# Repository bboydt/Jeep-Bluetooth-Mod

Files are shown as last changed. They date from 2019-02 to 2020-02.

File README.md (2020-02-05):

# Jeep Bluetooth Mod

## About
When I started driving, I wanted Bluetooth in my 2004 Jeep Grand Cherokee. Several years later, I finally got around to building a Bluetooth mod. My radio has a plug for a cd changer, so I used an Arduino and a Bluetooth module to make a pseudo cd changer. It took me about a month, however I procrastinated a lot. [Here's a video of the prototype working (ignore the awful music)](https://youtu.be/_DS7fCqb5ws).

## Useful Info

 - The arduino prototype code is in Jeep/ and the ATtiny version's code is in src/
 - My radio model is p05064354aj.
 - I'm using an Arduino UNO and a XS-3868 Bluetooth module
 - Chrysler radios, made before 2004, use the car’s internal PCI bus for communication with other accessories (i.e. a cd changer). It’s a good idea to be careful when writing to this bus because you could damage your car.
 - My car uses the J1850 VPW protocol.
 - Some good vocabulary to know for this protocol:
    - **Frame** : a packet of data
    - **Cyclical Redundancy Check (CRC)** : it’s a checksum
 - I used two optocouplers to communicate on the bus without frying my Arduino. Also, I put some LEDs on the optocouplers' outputs which was useful for debugging.

## Useful Links

 - [This has a lot of information on what to send to the radio to trick it into thinking you’re a cd changer.](https://www.mictronics.de/projects/cdc-protocols/#ChryslerJeep)
 - [This has good info on the J1850 protocol.](http://www.interfacebus.com/Automotive_SAE_J1850_Bus.html)
 - [A more technical document on J1850.](http://citeseerx.ist.psu.edu/viewdoc/download?doi=10.1.1.506.6682&rep=rep1&type=pdf)
 - [This guy’s project uses the same protocol so it was helpful.](https://github.com/connorwm/J1850VPW)
 - [Radio Pinout (there are also other radio pinouts here)](https://www.tehnomagazin.com/Auto-radio-car-connector/CHRYSLER-Car-Radio-Wiring-Connector.htm)

## Todo

 - Finish converting from the Arduino prototype to the ATtiny version
   - CRC check (Frame Creation in general)
   - Proper Responses to the radio
 - In the current configuration, the relay is unreliable so that needs to be fixed

----

*Benjamin Thomas - boydbt48@gmail.com - 2019*

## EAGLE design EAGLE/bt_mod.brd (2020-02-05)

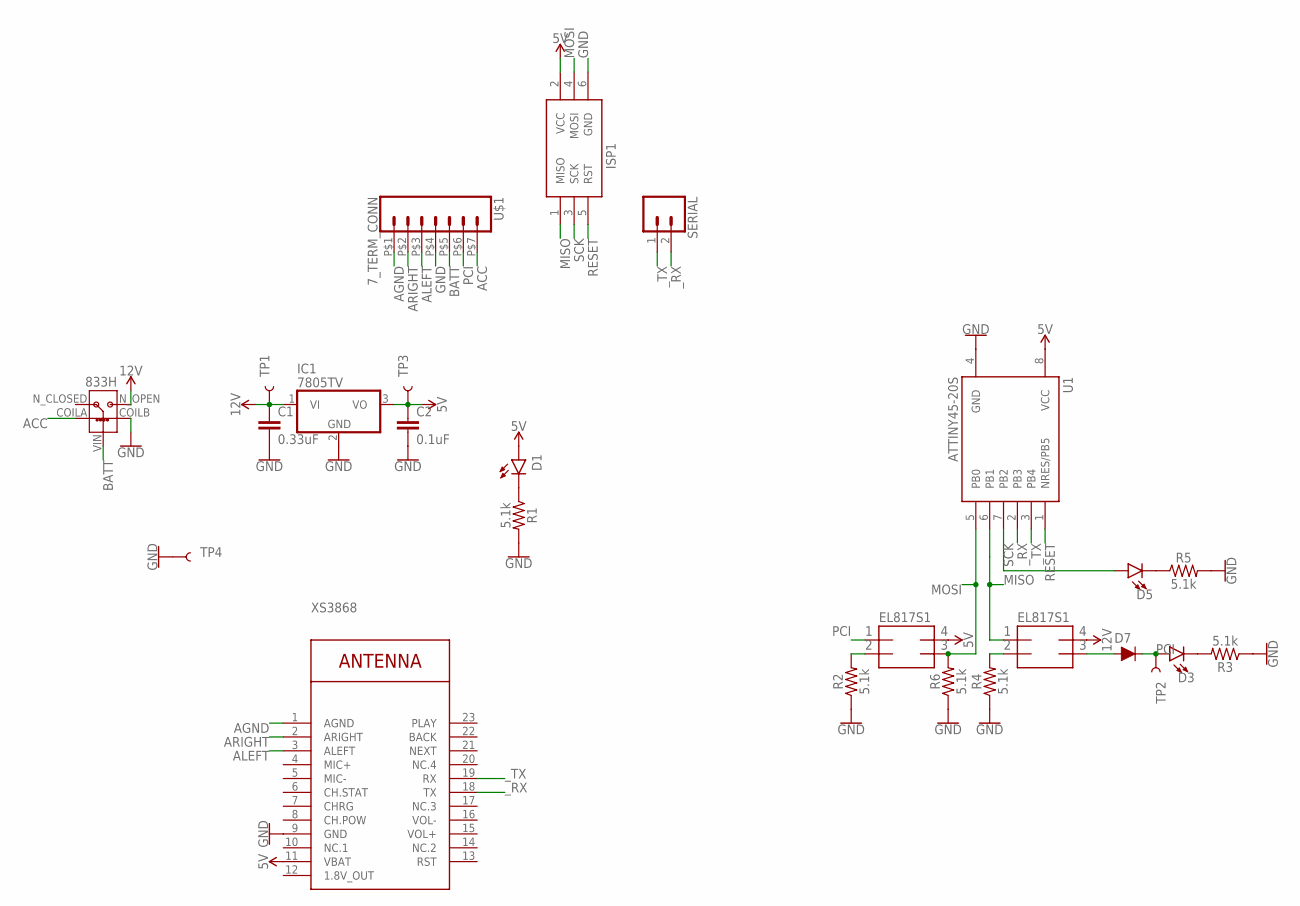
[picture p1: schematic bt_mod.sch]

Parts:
1: 833H-1C-C-12VDC
C1: 0.33uF; 0603
C2: 0.1uF; 0603
D1, D3, D5: LED0603; LED-0603
D7: 250mA/100V; SOD-323
IC1: 7805TV; TO220V
INPUT: EL3H7-G; SMD-4
ISP1: AVRISP-6; AVRISP
OUTPUT: EL3H7-G; SMD-4
R1, R2, R3, R4, R5, R6: 5.1k; 0603
SERIAL: CONN_02; 1X02
TP1, TP2, TP3, TP4: TEST-POINT3X5; PAD.03X.05
U1: ATTINY45-20S; SOIC8_EIAJ_208MIL
U$1: 7_TERM_CONN; 7_TERMINALS
XS3868: WIRELESS-BLUETOOTH-XS3868

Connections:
1.8V_OUT: XS3868.12 (1.8V_OUT)
5V: C2.1, D1.A, IC1.3 (VO), INPUT.P$4, ISP1.2 (VCC), TP3.P$1, U1.8 (VCC), XS3868.11 (VBAT)
12V: 1.N_OPEN, C1.1, IC1.1 (VI), OUTPUT.P$4, TP1.P$1
ACC: 1.COILA, U$1.P$7 (7)
AGND: U$1.P$1 (1), XS3868.1 (AGND)
ALEFT: U$1.P$3 (3), XS3868.3 (ALEFT)
ARIGHT: U$1.P$2 (2), XS3868.2 (ARIGHT)
BATT: 1.VIN, U$1.P$5 (5)
GND: 1.COILB, C1.2, C2.2, IC1.2 (GND), ISP1.6 (GND), R1.2, R2.1, R3.1, R4.1, R5.2, R6.1, TP4.P$1, U1.4 (GND), U$1.P$4 (4), XS3868.9 (GND)
MISO: ISP1.1 (MISO), OUTPUT.P$1, U1.6 (PB1)
MOSI: INPUT.P$3, ISP1.4 (MOSI), R6.2, U1.5 (PB0)
unnamed: D1.C, R1.1
unnamed: INPUT.P$2, R2.2
unnamed: OUTPUT.P$2, R4.2
unnamed: D5.C, R5.1
unnamed: D3.C, R3.2
unnamed: D7.A, OUTPUT.P$3
PCI: D3.A, D7.C, INPUT.P$1, TP2.P$1, U$1.P$6 (6)
RESET: ISP1.5 (RST), U1.1 (NRES/PB5)
RST: XS3868.13 (RST)
SCK: D5.A, ISP1.3 (SCK), U1.7 (PB2)
_RX: SERIAL.2, U1.2 (PB3), XS3868.18 (TX)
_TX: SERIAL.1, U1.3 (PB4), XS3868.19 (RX)

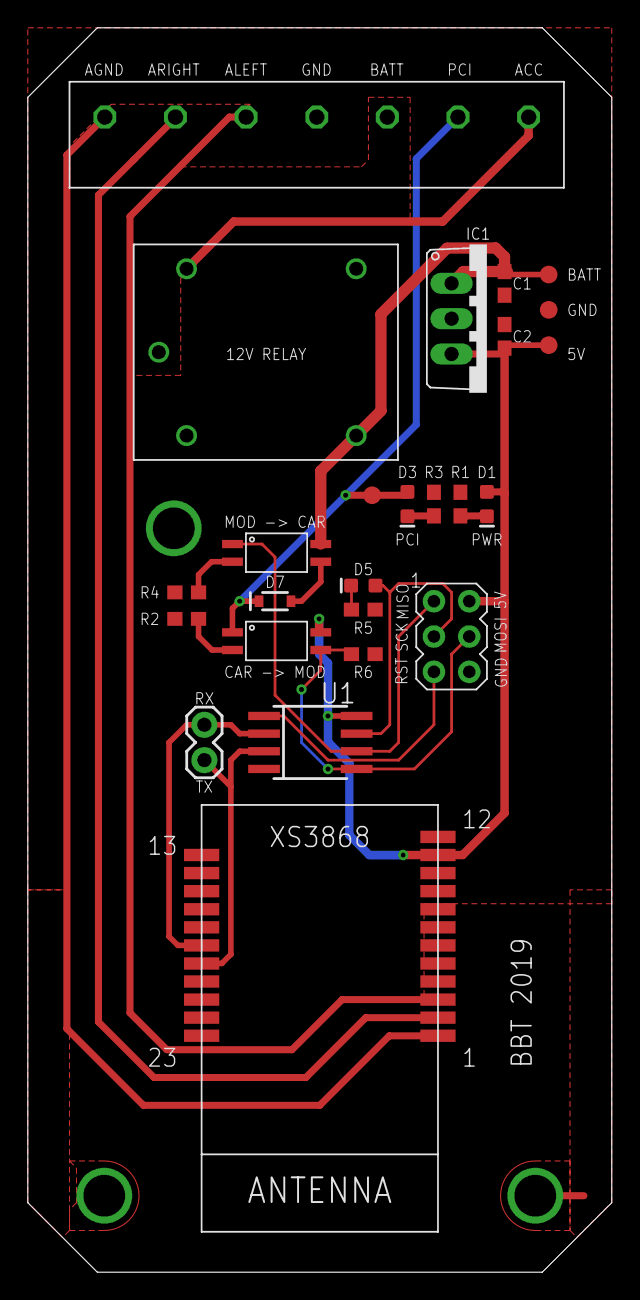
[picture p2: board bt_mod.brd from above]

Board: 2 copper layers, 42.0 x 89.5 mm, 25 parts (0 on the bottom side), 21 nets.

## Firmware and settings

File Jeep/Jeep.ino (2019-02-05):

// Jeep.ino
// Benjamin Thomas
// boydbt48@gmail.com
// Jan 2019
// A script that allows an Arduino to become a fake CD changer for a 2004 Jeep Grand Cherokee Radio.
// https://github.com/TildeOrange/Jeep-Bluetooth-Mod


// #define DEBUG_OUTPUT // Uncomment if you want debug info (might be slower)

#define PIN_IN 6
#define PIN_OUT 7
#define ERROR_TIMEDOUT -1
#define ERROR_INVALID_CRC -2

#define BUFF_LEN 16
byte buff[BUFF_LEN];

unsigned long last_sent = 0;

void setup()
{
#ifdef DEBUG_OUTPUT
	Serial.begin(9600);
#endif // DEBUG_OUTPUT

	pinMode(PIN_IN, INPUT);
	pinMode(PIN_OUT, OUTPUT);
	digitalWrite(PIN_OUT, LOW);
}

// A simple loop that checks for a poll frame from the radio and responds as if it was a CD changer. This opens up the audio input.
void loop()
{
	digitalWrite(PIN_OUT, LOW);   // just to be safe

	int bytes_read = read_frame(PIN_IN, buff, BUFF_LEN, 2000); // read from PIN_IN into the buff and timeout after 2 seconds

	if (0 < bytes_read && bytes_read <= 12)   // TODO figure out max length of frame
	{

#ifdef DEBUG_OUTPUT
        // print incoming frame (without check sum)
		Serial.print("Incoming frame: [ ");
		for (int i = 0; i < bytes_read - 1; i++)
		{
			Serial.print("0x" + String(buff[i], HEX) + " ");
		}
		Serial.println("]");
#endif // DEBUG_OUTPUT


		unsigned long current_time = millis();

		// If received frame is a poll from the radio or we haven't sent anything for a bit, then send a response frame.
		if (buff[0] == 0x8D || current_time - last_sent >= 1000)
		{
			int len = 5;
			byte buff[len] = { 0x8D, 0x94, 0x4, 0x14 };
			buff[len - 1] = CRC8(buff, len - 1);


#ifdef DEBUG_OUTPUT
            // print outgoing frame (with CRC)
			Serial.print("Outgoing frame: [ ");
			for (int i = 0; i < len; i++)
			{
				Serial.print("0x" + String(buff[i], HEX) + " ");
			}
			Serial.println("]");
#endif // DEBUG_OUTPUT

            // TODO wait for a quiet moment

			send_frame(PIN_OUT, buff, len);

			last_sent = current_time;
		}
	}
	else
	{
		switch (bytes_read)
		{
		case ERROR_TIMEDOUT:
			Serial.println("Timed out");
			break;
		case ERROR_INVALID_CRC:
			Serial.print("Read frame with an invalid CRC: [");
			for (int i = 0; i < 4; i++)
			{
				Serial.print("0x" + String(buff[i], HEX) + " ");
			}
			Serial.println("]");
			break;
		default:
			Serial.println("Read too many/few bytes" + String(bytes_read));
			break;
		}
	}
	//*/
}

// Disclaimer:
// This is a copy of a function written by Michael Wolf for the AVR J1850 VPW Interface he wrote. (https://www.mictronics.de/projects/j1850-vpw-interface/)
// I do not understand this so best of luck to you if it breaks.
//
// Creates an 8 bit cyclical redundancy check (CRC) from a bunch of bytes.
// The CRC can be used to check the validaty of those bytes durring transmission and is used to verify received data.
//
// byte *buff : data used to create CRC
// int len    : length of data
byte CRC8(byte *buff, int len)
{
	byte crc_reg = 0xff;
	byte poly;
	byte byte_count;
	byte bit_count;
	byte *byte_point;
	byte bit_point;

	for (byte_count = 0, byte_point = buff; byte_count < len; ++byte_count, ++byte_point)
	{
		for (bit_count = 0, bit_point = 0x80; bit_count < 8; ++bit_count, bit_point >>= 1)
		{
			if (bit_point & *byte_point)         // case for new bit = 1
			{
				if (crc_reg & 0x80)
				{
					poly = 1;             // define the polynomial
				}
				else
				{
					poly = 0x1c;
				}

				crc_reg = ((crc_reg << 1) | 1) ^ poly;
			}
			else         // case for new bit = 0
			{
				poly = 0;
				if (crc_reg & 0x80)
				{
					poly = 0x1d;
				}
				crc_reg = (crc_reg << 1) ^ poly;
			}
		}
	}
	return ~crc_reg;
}

// TODO remove this complicated mess
//
// Measures how long, in microseconds, a voltage was held.
// Blocks until the pin's voltage changes or the timeout is reached.
// Returns the time in microseconds that the voltage was constant.
//
// int pin                  : the pin to watch
// int initial_voltage      : what the voltage currenly is
// unsigned long start_time : when the voltage first became the initial voltage in microseconds (set to 0 if you aren't too concerned about accruacy)
// unsigned long timeout    : how many microseconds is too long to wait (warning: using this will add some overhead and decrease accruacy)
unsigned long get_signal_length(int pin, int initial_voltage, unsigned long start_time, unsigned long timeout)
{
	unsigned long start = start_time != 0 ? start_time : micros();

	if (timeout > 0)
	{
		unsigned long elapsed_time;

		// wait for voltage to change
		while (digitalRead(pin) == initial_voltage && elapsed_time < timeout)
		{
			elapsed_time = micros() - start;
		}

		return elapsed_time;
	}
	else
	{
		while (digitalRead(pin) == initial_voltage) {}
		return micros() - start;
	}
}

// Bit Symbols Cheat Sheet
// High for 64uS  = 1
// Low  for 128uS = 1
// High for 128uS = 0
// Low  for 64uS  = 0

// Reads a frame into a byte buffer.
// Blocks until a response was found or the timeout is reached.
// Returns the number of bytes read or ERROR_TIMEDOUT if the timeout was reached.
//
// int pin               : the pin to watch
// byte *buff            : the buffer to write into
// int len               : the length of the buffer
// unsigned long timeout : how many milliseconds is too long to wait
int read_frame(int pin, byte *buff, int len, unsigned long timeout)
{
	unsigned long start_time = millis();
	bool found_EOD = false;
	unsigned long signal_length;
	unsigned long signal_end = 0L;
	int current_voltage = LOW;   // we expect this to be low after the SOF signal
	String bits_str = "";

	// look for SOF signal (high for 200uS)
	while (signal_end == 0L)
	{
		while (digitalRead(pin) != HIGH)
		{
			if (millis() - start_time >= timeout)
			{
				return ERROR_TIMEDOUT;
			}
		}

		signal_length = get_signal_length(pin, HIGH, 0, timeout);

		if (abs(signal_length - 200) <= 15)     // if the signal length was 200uS +/- 15uS, then this is a valid signal
		{
			signal_end = micros();
			break;
		}

		if (millis() - start_time >= timeout)
		{
			return ERROR_TIMEDOUT;
		}
	}

	while (!found_EOD)
	{
		current_voltage = digitalRead(PIN_IN);
		signal_length = get_signal_length(pin, current_voltage, signal_end, 300);
		signal_end = micros();

		if (signal_length <= 96)
		{
			if (current_voltage == HIGH)
			{
				bits_str += '1';
			}
			else
			{
				bits_str += '0';
			}
		}
		else if (signal_length <= 164)
		{
			if (current_voltage == LOW)
			{
				bits_str += '1';
			}
			else
			{
				bits_str += '0';
			}
		}
		else if (current_voltage == LOW && signal_length > 164)
		{
			found_EOD = true;
		}
	}

	// parse data
	size_t bit_count = bits_str.length();
	size_t byte_count = bit_count / 8;

	for (int p = 0; p < byte_count; p++)
	{
		for (int b = p * 8; b < (p + 1) * 8; b++)
		{
			buff[p] <<= 1;
			if (bits_str[b] == '1')
			{
				buff[p]++;
			}
		}
	}

	if (buff[byte_count - 1] != CRC8(buff, byte_count - 1))
	{
		return ERROR_INVALID_CRC;
	}

	return (int)byte_count;
}

// TODO avoid talking over other accessories
// Sends a frame.
// Make the last byte in data is a CRC for the data.
//
// int pin    : the pin to write to
// byte *buff : the buffer to write from
// int len    : the length of the buffer
void send_frame(int pin, byte *data, int len)
{
	int current_voltage = LOW;

	// parse data (we do that now to speed up sending the data)
	byte t[len * 8];   // delays
	for (int p = 0; p < len; p++)
	{
		for (int b = 0; b < 8; b++)
		{
			if (((data[p] >> 7 - b) & 1) == 0)         // if bit is 0
			{
				t[p * 8 + b] = (current_voltage == LOW) ? 64 : 128;
			}
			else
			{
				t[p * 8 + b] = (current_voltage == HIGH) ? 64 : 128;
			}
			current_voltage = (current_voltage == LOW) ? HIGH : LOW;
		}
	}

	current_voltage = LOW;

	// send SOF
	digitalWrite(pin, HIGH);
	delayMicroseconds(200);
	digitalWrite(pin, LOW);

	// send data
	for (int b = 0; b < len * 8; b++)
	{
		current_voltage = (current_voltage == LOW) ? HIGH : LOW;
		delayMicroseconds(t[b]);
		digitalWrite(pin, current_voltage);
	}

	// send EOF
	digitalWrite(pin, LOW);
	delayMicroseconds(280);
}

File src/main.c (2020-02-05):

#define F_CPU 8000000UL

#define SET_HIGH(pin) PORTB |= _BV(pin)
#define SET_LOW(pin) PORTB &= ~_BV(pin)
#define TOGGLE_PIN(pin) PORTB ^= _BV(pin)

#define IN_PIN  0
#define OUT_PIN 1
#define LED_PIN 2
#define RX_PIN 	3
#define TX_PIN 	4

#include <avr/io.h>
#include <avr/interrupt.h>
#include <util/delay.h>

void SendFrame(const uint8_t *data, uint8_t len);

int main()
{
    // setup pins and enable interrupts
    DDRB = _BV(OUT_PIN) | _BV(LED_PIN) | _BV(TX_PIN);
    PORTB = 0;

    const uint8_t frameA_data[4] = { 0x55, 0x55, 0x55, 0x55 };
	const uint8_t frameB_data[4] = { 0x11, 0x00, 0x33, 0xff };

    while (1)
    {
        _delay_ms(500);
        SET_HIGH(LED_PIN);
        SendFrame(frameA_data, 4);
        _delay_us(500);
        SendFrame(frameB_data, 4);
        SET_LOW(LED_PIN);
    }
}


//
// J1850 Protocall stuffs
//

// Timing
#define PIN_CHANGE_DELAY 1
 // I'm not sure the cause of this, but there is a 12 (or 8?) us delay but only for the start of frame signal, so we account for that here
#define START_OF_FRAME_LEN 200 - PIN_CHANGE_DELAY - 12
#define END_OF_FRAME_LEN 200 - PIN_CHANGE_DELAY - 12
#define ACTIVE_LOGIC_1_LEN 64 - PIN_CHANGE_DELAY
#define ACTIVE_LOGIC_0_LEN 128 - PIN_CHANGE_DELAY
#define PASSIVE_LOGIC_1_LEN 128 - PIN_CHANGE_DELAY
#define PASSIVE_LOGIC_0_LEN 64 - PIN_CHANGE_DELAY

void SendFrame(const uint8_t *data, uint8_t len)
{
    SET_HIGH(OUT_PIN);
    _delay_us(200);
    uint8_t byte = 0;
    uint8_t bit = 0;
    for (byte = 0; byte < len; byte++)
    {
        for (bit = 0; bit < 8; bit++)
        {
            TOGGLE_PIN(OUT_PIN);
            if (bit % 2 == 0)
            {
                // passive logic
                _delay_us(PASSIVE_LOGIC_1_LEN);
            }
            else
            {
                // active logic
                _delay_us(ACTIVE_LOGIC_1_LEN);
            }
        }
    }
    SET_LOW(OUT_PIN);
    _delay_us(200);
}

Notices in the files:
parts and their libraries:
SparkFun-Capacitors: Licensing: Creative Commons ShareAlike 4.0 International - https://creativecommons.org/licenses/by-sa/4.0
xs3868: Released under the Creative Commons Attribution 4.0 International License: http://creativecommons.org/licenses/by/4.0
